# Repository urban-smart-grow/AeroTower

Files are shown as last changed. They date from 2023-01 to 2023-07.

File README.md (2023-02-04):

# AeroTower

The AeroTower is inspired by similar projects like [this one](https://www.thingiverse.com/thing:2403922),
but makes use of aeroponics instead of hydroponics. 
If you want to know more about it or build your own, [head over to the documentation site](https://urban-smart-grow.github.io/website/aerotower)

## Getting Started

Open in Gitpod (https://gitpod.io/#https://github.com/urban-smart-grow/AeroTower)

The easiest way to get started is to edit this repository on gitpod. 
Alternatively you can spin up a local environment with the help of [devcontainers](https://code.visualstudio.com/docs/devcontainers/containers).

Once your workspace environment is set up, open the file of the part you want to modify from the `/src`-folder.
If you run this file with python, a `STL`-file is generated and saved to the `/exports`-folder. 
You can open these `STL`-files beside your code to view your changes.

You can use nodemon to automate the rendering process. The `STL`-viewer will update automatically.

`nodemon src/body.py`

## Trivia

This project is a complete redesign of [this project](https://github.com/mfillmer/3d-modelling/tree/master/smart_grow/aero_tower).
The legacy project was more of a playground and was built upon SolidPython. 

This project is more focused and uses [CADQuery 2](https://cadquery.readthedocs.io/en/latest/index.html) 
with the excellent [cq_warehouse plugin](https://cq-warehouse.readthedocs.io/en/latest/).

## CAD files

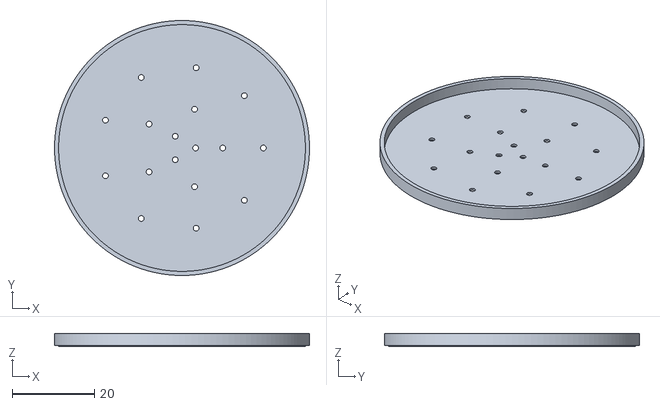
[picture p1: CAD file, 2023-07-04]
exports/plant_cup_lid.stl
62.0 x 62.0 x 3.25

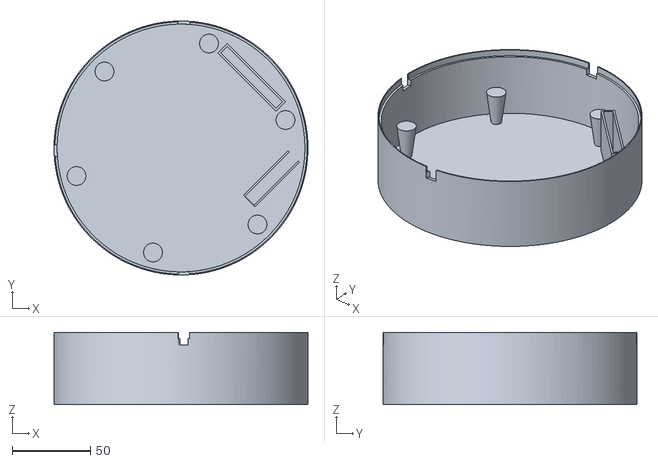
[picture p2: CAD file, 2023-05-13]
exports/solar_module_case.stl
162.0 x 162.0 x 46.0

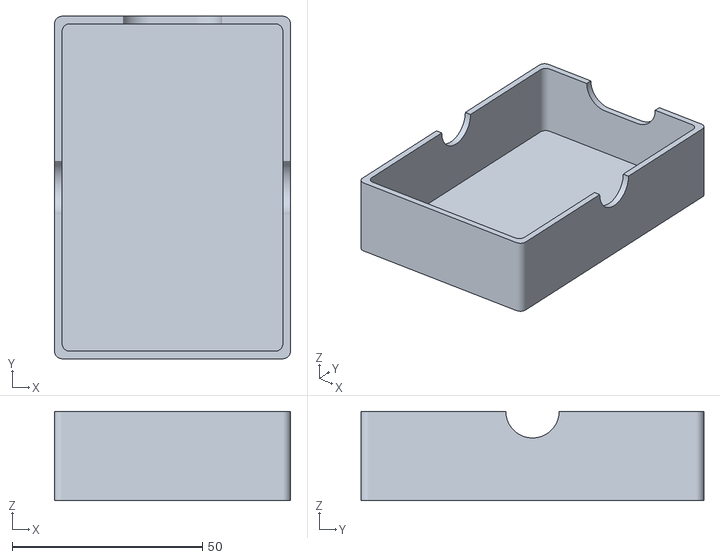
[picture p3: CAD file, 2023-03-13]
exports/head_electronics_case.stl
62.0 x 90.0 x 23.5

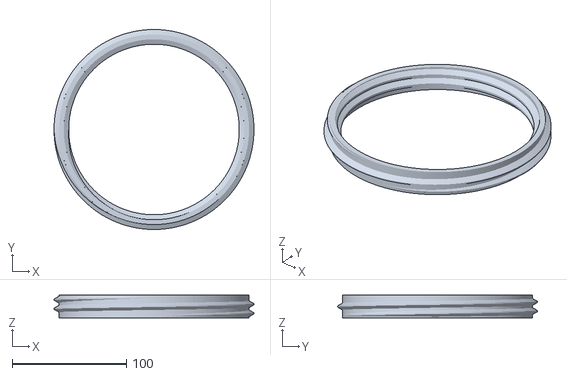
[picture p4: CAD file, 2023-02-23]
exports/tank_adapter.stl
175.2 x 175.2 x 20.0

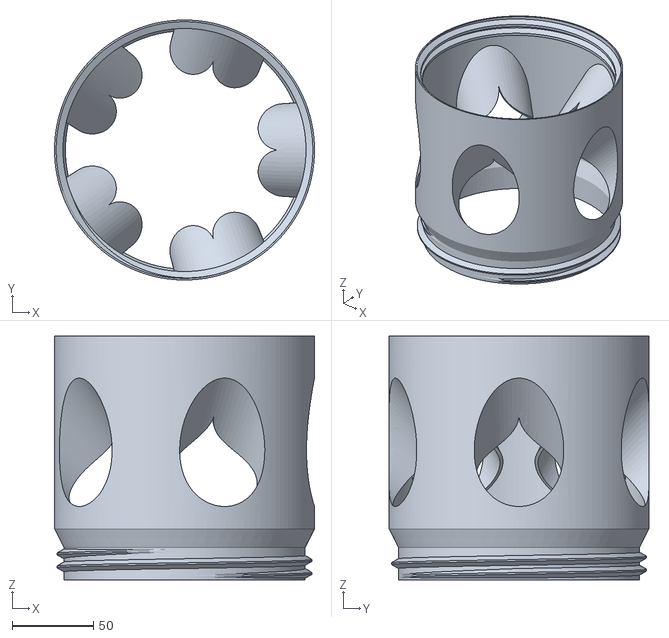
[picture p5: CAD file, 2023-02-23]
exports/body.stl
160.0 x 160.0 x 150.0

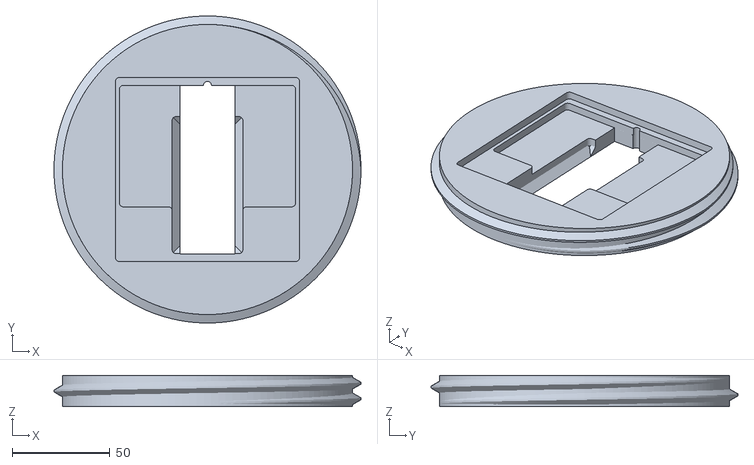
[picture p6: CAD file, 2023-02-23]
exports/head_mount.stl
157.2 x 157.2 x 16.0

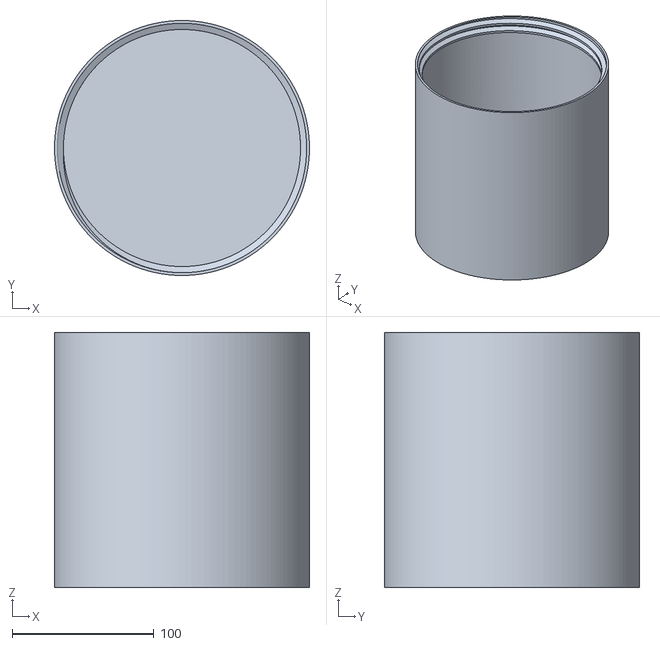
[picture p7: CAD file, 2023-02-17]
exports/tank.stl
180.0 x 179.9 x 180.0

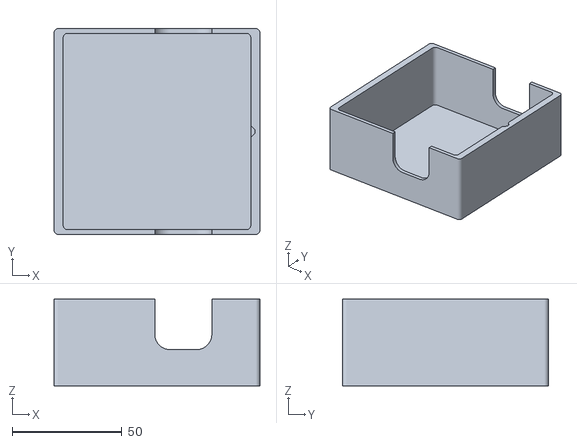
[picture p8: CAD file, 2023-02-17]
exports/head_electronics_lid.stl
94.0 x 94.0 x 39.5

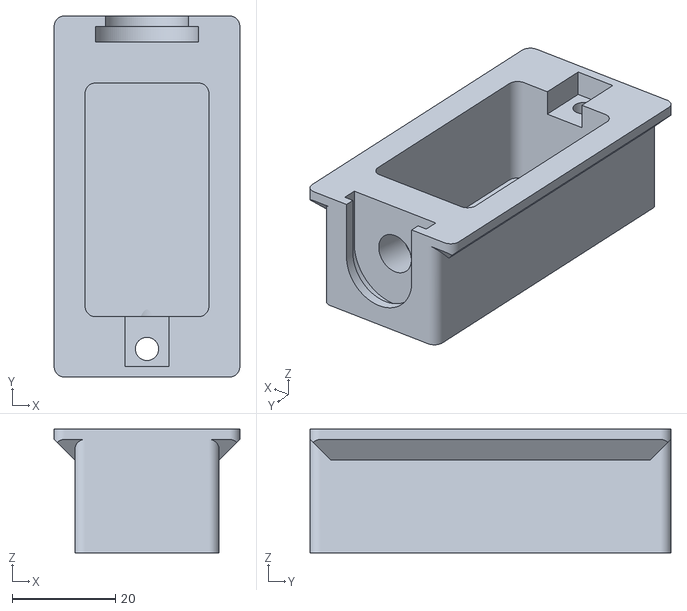
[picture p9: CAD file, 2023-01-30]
exports/head_tank.stl
36.0 x 70.0 x 24.0

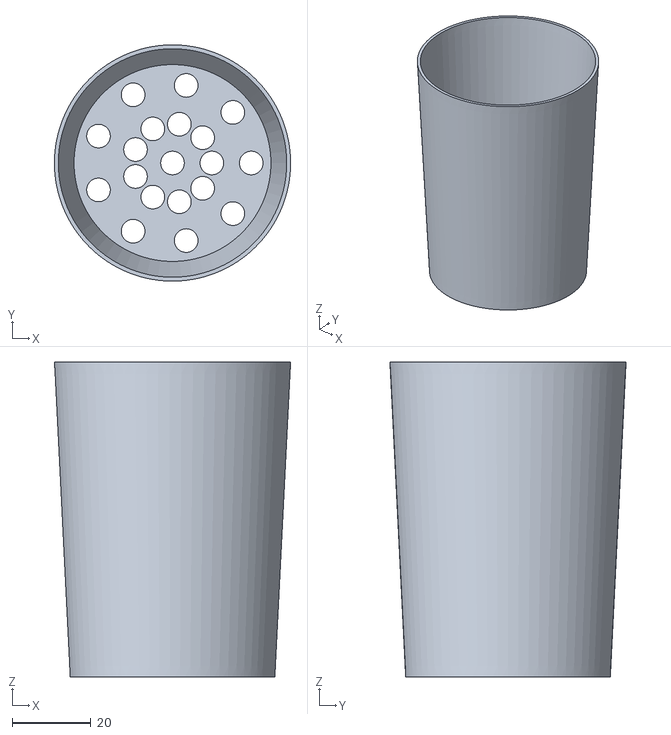
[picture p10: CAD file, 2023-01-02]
exports/plant_cup.stl
60.0 x 60.0 x 80.0

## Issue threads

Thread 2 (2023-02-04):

Add gaps between threads for smoother assembly

mfillmer, 2023-02-04:
At the moment, the threads are sized to fit their counterparts exactly.
While this works, it makes the assembly of 3D printed parts more difficult.

Below are all parts listed, that use a thread to connect to other parts:
- tank
- tank_adapter
- body
- head_mount

A gap of 0.2 millimeters should be sufficient, while also keeping the tower tight enough to hold the fog.

Closed 2023-02-16.

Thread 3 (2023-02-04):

Sink cups deeper into body

mfillmer, 2023-02-04:
At the moment, the cups fit exactly into the body, so that both parts are flush with each other at the bottom end.

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

The legacy vesion of the body allowed the cups to be mounted more deeply, adding stability and tightness.

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

The body should be modified, so that each cup can be sunk one centimeter into the body.

Closed 2023-02-10.

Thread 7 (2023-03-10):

Remove cable cutout from electronics case

mfillmer, 2023-03-10:
The cable cutout on the bottom of the [electronics case](https://github.com/urban-smart-grow/AeroTower/blob/167bae4f82490244af1cde0fe1fb61e13ed3d9c0/src/head_electronics_case.py) is not longer needed.
It can be removed and the extra height can be removed, resulting in a base height of 2mm.

squawnchy, 2023-03-10:
Why is it possible to do without the inlets?

squawnchy, 2023-03-10:
Can all the inlets be removed? (front, side and bottom)

mfillmer, 2023-03-11:
Hi, good questions!

Only the channels on the bottom of the case can be removed, as the cables do not get squeezed at this side.
It is also the only side, where extra material is added to make the cutout possible.

Below are images for further illustration.

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

Closed 2023-03-13.

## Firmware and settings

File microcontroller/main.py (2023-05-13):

import time
import board
from digitalio import DigitalInOut, Direction
 
led = DigitalInOut(board.LED_INVERTED)
led.direction = Direction.OUTPUT
 
pump = DigitalInOut(board.D9)
pump.direction = Direction.OUTPUT
pump_pause = 5*60
pump_interval = 2
pulse_intensity = 0.002
 
atomizer = DigitalInOut(board.D8)
atomizer.direction = Direction.OUTPUT
fog_interval = 60
fog_pause = fog_interval + 60 * 5
 
delays = dict()
workers = dict()
 
def set_interval(delay, callback, key):
    def execute():
        if delays.get(key, 0) <= time.monotonic():
            callback()
            delays[key] = time.monotonic() + delay
 
    workers[key] = execute
 
 
def set_timeout(delay, callback, key):
    delays[key] = time.monotonic() + delay
 
    def execute():
        if not key in delays.keys():
            return
        if delays[key] <= time.monotonic():
            callback()
            del delays[key]
 
    workers[key] = execute
 
 
def turn_pump_on_by_pwm(duration=pump_interval, pulse=pulse_intensity):
    led.value = False
    t_end = time.monotonic() + duration
    while time.monotonic() < t_end:
        pump.value = True
        time.sleep(pulse)
        pump.value = False
        time.sleep(pulse)
    led.value = True
 
 
def turn_atomizer_off():
    atomizer.value = False
 
 
def turn_atomizer_on(duration=fog_interval):
    atomizer.value = True
    set_timeout(duration, turn_atomizer_off, 'FOG_OFF')
 
 
set_interval(pump_pause, turn_pump_on_by_pwm, 'PUMP_ON')
set_interval(fog_pause, turn_atomizer_on, 'FOG_ON')
turn_pump_on_by_pwm(10)
 
while True:
    for execute in workers.values():
        execute()

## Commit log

2022-12-29 make plant cup with cadquery
    [plant_cup.stl]
2022-12-29 refactor plant_cup
    [plant_cup.stl]
2022-12-30 add tank with threads
    [tank.stl]
2023-01-02 use solids for hollow cone
    [plant_cup.stl, tank.stl]
2023-01-02 play with rotation
    [body.stl]
2023-01-02 start body
    [body.stl]
2023-01-03 add drop cuts
    [body.stl]
2023-01-03 make socket offset perfect
    [body.stl]
2023-01-03 add threads
    [body.stl]
2023-01-03 add gap, render with 5 cups
    [body.stl]
2023-01-03 add tank adapter
    [tank_adapter.stl]
2023-01-04 start head
    [head.stl]
2023-01-05 add pump mount
    [head.stl]
2023-01-05 adjust dimensions, add pump case
    [head.stl]
2023-01-05 fix holes
    [head.stl]
2023-01-05 add inlet for pump
    [head.stl]
2023-01-06 fix dimensions
    [head.stl]
2023-01-06 start electronic mount
    [head_electronics_case.stl]
2023-01-08 move xiao mounts to edge, comment points
    [head_electronics_case.stl]
2023-01-10 add cable management
    [head_electronics_case.stl]
2023-01-10 add mounts, improve dimensions
    [head_electronics_case.stl, head_tank.stl]
2023-01-11 add lid for head
    [head_electronics_lid.stl]
2023-01-13 add head mount
    [head_mount.stl]
2023-01-13 add assembly for showcase
2023-01-14 update gaps
    [body.stl, head_mount.stl]
2023-01-17 thicker sockets
    [body.stl]
2023-01-22 redesign for breadboard
    [head_electronics_case.stl, head_tank.stl]
2023-01-24 start new lid
    [head_electronics_lid.stl]
2023-01-26 finish lid
    [head_electronics_lid.stl]
2023-01-29 update dimensions
    [head_electronics_case.stl, head_electronics_lid.stl]
2023-01-29 finish wings on head tank
    [head_tank.stl]
2023-01-30 update cutouts
    [head_electronics_lid.stl, head_mount.stl, head_tank.stl]
2023-01-30 remove placeholder tank
    [head_mount.stl]
2023-01-31 finish head mount
    [head_mount.stl]
2023-01-31 reduce gap
    [head_mount.stl]
2023-01-31 make tank inlet more precise, reduce material, deepen inlets
    [head_mount.stl]
2023-01-31 add piezo cable hole
    [head_mount.stl]
2023-02-02 simplify case lid
    [head_electronics_lid.stl]
2023-02-03 make body shorter
    [body.stl]
2023-02-10 make cup sockets wider, closes #3
    [body.stl]
2023-02-16 make external threads smaller, add 0.2mm gap between threads
    [body.stl, head_mount.stl, tank.stl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]
2023-02-17 adjust assembly
2023-02-17 fresh build
    [head_electronics_case.stl, head_electronics_lid.stl, tank.stl]
2023-02-23 increase gaps
    - increase thread gap to 0.4mm
    - add console logging to check thread fitting more easily
    - improve assembly
    - add explosion view
    - fresh build
    [body.stl, head_mount.stl, tank_adapter.stl]
2023-03-13 remove bottom channel from head electronic case
    [head_electronics_case.stl]
2023-05-13 feat(10): add solar powerbank module (#11)
    * start solar module case
    * add sockets for solar charger, battery and cable hole
    * add cable hooks
    * move cable holes to the side
    [solar_module_case.stl]
2023-07-04 add plant_cup_lid
    [body.stl, head_electronics_case.stl, head_electronics_lid.stl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]
2023-07-04 improve design
    [plant_cup_lid.stl]
